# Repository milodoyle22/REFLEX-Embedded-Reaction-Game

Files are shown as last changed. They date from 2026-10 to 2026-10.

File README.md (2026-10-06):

# REFLEX - Embedded Reaction-Time Game

REFLEX is a five-round embedded reaction-time game built around an Arduino Mega 2560. It combines embedded C++, digital electronics, transistor-switched illuminated arcade controls, a 16x2 LCD, audio feedback, permanent perfboard hardware, and a custom enclosure designed in Fusion 360 for 3D printing.

> **Build status:** Core electronics, firmware, perfboard transfer, and enclosure CAD are complete. Final enclosure assembly and full-system validation are still in progress.

## Demo

A working breadboard prototype demonstrates randomized cues, reaction-time measurement, scoring, LCD feedback, and wrong-button handling before the design was transferred to permanent hardware.

**[Watch the REFLEX breadboard prototype demo](docs/demo/REFLEX_Prototype_Demo.mp4)**

## Engineering Highlights

- Built a complete five-round reaction game around an Arduino Mega 2560
- Structured the firmware as a finite-state machine rather than a blocking sequence
- Replaced the original blocking wait logic with non-blocking timing so early presses can be detected
- Measured the illuminated arcade-button LED load at approximately **22 mA**
- Added three 2N2222A NPN low-side driver stages instead of placing the LED load directly on MCU GPIO
- Used Arduino internal pull-ups for simple, reliable active-low button inputs
- Migrated the validated breadboard circuit to soldered perfboard with dedicated +5 V and GND distribution
- Designed a serviceable enclosure in Fusion 360 around the real component dimensions

## System Overview

| Subsystem | Implementation |
| --- | --- |
| Controller | Arduino Mega 2560 |
| Inputs | Red, green, blue, and START arcade-button switches |
| Outputs | 3 illuminated color cues, 16x2 LCD, passive buzzer |
| LED drivers | 3x 2N2222A NPN transistor low-side switches |
| Permanent hardware | Custom soldered perfboard |
| Mechanical design | Fusion 360 enclosure for 3D printing |
| Power | Designed for internal USB power-bank operation |

### Signal Map

| Function | Arduino Pin |
| --- | ---: |
| Blue LED driver | D4 |
| Green LED driver | D5 |
| Red LED driver | D6 |
| Red button | D8 |
| Green button | D9 |
| Blue button | D10 |
| START button | D11 |
| Passive buzzer | D12 |
| LCD RS | D22 |
| LCD E | D23 |
| LCD D4 | D24 |
| LCD D5 | D25 |
| LCD D6 | D26 |
| LCD D7 | D27 |

## Firmware Architecture

The firmware uses five states:

~~~mermaid
stateDiagram-v2
    [*] --> IDLE
    IDLE --> WAITING: START
    WAITING --> RESULT: false start
    WAITING --> CUE_ACTIVE: randomized wait expires
    CUE_ACTIVE --> RESULT: correct or wrong input
    RESULT --> WAITING: next round
    RESULT --> GAME_OVER: round 5 complete
    GAME_OVER --> IDLE: START / reset
~~~

- **IDLE** - waits for the player to start
- **WAITING** - runs a randomized 2-5 second delay while still checking for false starts
- **CUE_ACTIVE** - activates one randomized color cue and measures response time
- **RESULT** - reports the round result and waits to continue
- **GAME_OVER** - displays final score and average successful reaction time

Reaction time is captured with **micros()**, while the waiting state uses non-blocking **millis()** timing so the program can continue checking inputs before the cue appears.

## Hardware Design

The illuminated arcade-button LEDs were measured at approximately **22 mA**. REFLEX therefore uses a transistor stage for each colored LED instead of driving the load directly from an Arduino output.

~~~text
Arduino output -> 1 kOhm -> transistor base
+5 V -> 220 Ohm -> button LED +
button LED - -> transistor collector
transistor emitter -> GND
~~~

The red, green, blue, and START switches use **INPUT_PULLUP**, so each input is HIGH when released and LOW when pressed. The white START-button LED is continuously illuminated as a status indicator.

## Development Process

The project was developed and validated incrementally:

1. Breadboarded the LCD, buzzer, input buttons, and cue LEDs
2. Wrote and debugged the initial reaction-game firmware
3. Identified the limitation of a blocking randomized delay
4. Reworked the game flow into a non-blocking finite-state machine
5. Measured the arcade-button LED current and added transistor drivers
6. Tested all three color-driver channels
7. Transferred the working circuit to soldered perfboard
8. Designed the enclosure around the actual Mega, perfboard, LCD, controls, and power hardware
9. Exported the printable enclosure parts and submitted them for 3D printing

## CAD Files

Printable enclosure exports are available in [cad/stl/](cad/stl/):

- [REFLEX_Shell.stl](cad/stl/REFLEX_Shell.stl)
- [REFLEX_Cover.stl](cad/stl/REFLEX_Cover.stl)
- [REFLEX_Coupon.stl](cad/stl/REFLEX_Coupon.stl)

The coupon is a small print used to validate fit/tolerance before committing to the full enclosure print.

## Repository Structure

~~~text
REFLEX-Embedded-Reaction-Game/
|-- README.md
|-- firmware/
|   |-- REFLEX.ino
|   `-- README.md
|-- hardware/
|   |-- README.md
|   `-- pinout.md
|-- cad/
|   |-- README.md
|   `-- stl/
|-- docs/
|   |-- demo/
|   `-- images/
`-- bom/
    `-- BOM.md
~~~

## Current Build Status

- [x] Breadboard prototype
- [x] Core game firmware
- [x] Non-blocking FSM timing
- [x] LCD interface
- [x] False-start and wrong-button logic
- [x] Transistor LED drivers
- [x] Perfboard transfer
- [x] Three-channel LED hardware test
- [x] Fusion 360 enclosure design
- [x] STL exports
- [x] Enclosure submitted for 3D printing
- [x] Breadboard prototype demo video
- [ ] Final enclosure assembly
- [ ] Final integrated system test
- [ ] Final assembled-device photos
- [ ] Final assembled-device demo

## Tools and Technologies

**Hardware:** Arduino Mega 2560, 2N2222A transistors, 16x2 LCD, illuminated arcade buttons, passive buzzer, perfboard

**Software:** Arduino IDE, C++, Fusion 360, Git/GitHub

**Test Equipment:** Digital multimeter, oscilloscope, bench power supply

**Fabrication:** Breadboarding, soldering, perfboard assembly, 3D printing

## Author

**Milo Doyle**  
Electrical Engineering Student  
California State University, Long Beach  
Expected Graduation: May 2028

---

This repository documents an ongoing engineering build. Final enclosure photos and integrated-system results will be added after assembly.

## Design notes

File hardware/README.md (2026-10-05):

# Hardware

This directory documents the electrical design and permanent perfboard implementation for REFLEX.

## Subdirectories
- `schematic/` - circuit diagrams and electrical schematics
- `perfboard/` - perfboard layout and build documentation
- `wiring/` - wiring diagrams and harness documentation

## Major Hardware
- Arduino Mega 2560
- 3 x 2N2222A NPN transistor LED drivers
- 3 x 1 kOhm transistor base resistors
- 5 x 220 Ohm LED/backlight current-limiting resistors
- 4 x illuminated arcade buttons
- 16x2 HD44780-style LCD
- 10 kOhm LCD contrast potentiometer
- passive buzzer
- custom perfboard
- internal USB power bank

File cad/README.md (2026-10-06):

# CAD

Mechanical design files for the REFLEX enclosure.

## Design Tool

Autodesk Fusion 360

## Printable Parts

STL exports are stored in [stl/](stl/):

- **REFLEX_Shell.stl** - main enclosure body
- **REFLEX_Cover.stl** - removable cover
- **REFLEX_Coupon.stl** - small fit/tolerance test print

## Design Requirements

The enclosure was designed around the Arduino Mega 2560, custom perfboard, 16x2 LCD, four 30 mm illuminated arcade buttons, an internal slim USB power bank, and a short USB-A to USB-B power cable.

The layout prioritizes service access and keeps the Mega, perfboard, and battery from being stacked directly on top of one another.

The enclosure has been submitted for 3D printing; final fit and full-system assembly are still pending.

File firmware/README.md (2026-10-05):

# Firmware

This directory contains the Arduino firmware for REFLEX.

## Target
- Arduino Mega 2560
- Arduino IDE
- C++

## Main Firmware
The final game firmware will live here as `REFLEX.ino`.

The firmware implements the game as a finite-state machine and handles button inputs, random cue timing, reaction-time measurement, false starts, wrong-button responses, scoring, LCD output, buzzer feedback, and illuminated button control.

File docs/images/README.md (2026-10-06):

# Project Images

This directory contains development photos from the REFLEX build.

## Current Photos

The current files document the breadboard-prototype stage and are retained as original HEIC captures in the **raw/** folder.

Key prototype shots include:

- **breadboard-start-screen.HEIC**
- **breadboard-hardware-closeup.HEIC**
- **breadboard-wrong-button.HEIC**
- **breadboard-game-over.HEIC**

Additional development photos are also retained in **raw/**.

Final assembled-device photos will be added after the enclosure is printed and the complete system is integrated. JPG/PNG versions of the strongest images can then be embedded directly in the main README.

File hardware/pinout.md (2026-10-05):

# REFLEX Pinout

## Arduino Mega 2560

| Function | Pin | Direction |
| --- | ---: | --- |
| Blue LED transistor driver | D4 | Output |
| Green LED transistor driver | D5 | Output |
| Red LED transistor driver | D6 | Output |
| Red arcade switch | D8 | Input pull-up |
| Green arcade switch | D9 | Input pull-up |
| Blue arcade switch | D10 | Input pull-up |
| START arcade switch | D11 | Input pull-up |
| Passive buzzer | D12 | Output |
| LCD RS | D22 | Output |
| LCD E | D23 | Output |
| LCD D4 | D24 | Output |
| LCD D5 | D25 | Output |
| LCD D6 | D26 | Output |
| LCD D7 | D27 | Output |

## Arcade Button Wiring

### Red / Green / Blue LED Channels

```text
Arduino output -> 1 kOhm -> NPN base
NPN emitter -> GND
NPN collector -> button LED negative
+5 V -> 220 Ohm -> button LED positive
```

### Switch Inputs

```text
Arduino input -> switch -> GND
```

The firmware uses `INPUT_PULLUP`, so released = HIGH and pressed = LOW.

## White START Button

```text
D11 -> switch -> GND

+5 V -> 220 Ohm -> START LED +
START LED - -> GND
```

The white START LED is always illuminated while the system is powered.

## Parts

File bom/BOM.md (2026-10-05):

# Bill of Materials

## Core Electronics

| Qty | Component | Notes |
| ---: | --- | --- |
| 1 | Arduino Mega 2560 | Main microcontroller |
| 1 | 16x2 LCD | HD44780-style character display |
| 4 | 30 mm illuminated arcade buttons | Red, green, blue, white |
| 3 | 2N2222A NPN transistors | Colored LED switching |
| 3 | 1 kOhm resistors | Transistor base resistors |
| 5 | 220 Ohm resistors | Arcade LEDs + LCD backlight |
| 1 | 10 kOhm potentiometer | LCD contrast |
| 1 | Passive buzzer | Audio feedback |
| 1 | Perfboard | Permanent circuit assembly |
| 1 | USB power bank | Internal power source |
| 1 | Short USB-A to USB-B cable | Power bank to Arduino Mega |

## Fabrication / Wiring
- hookup wire / jumper wire
- solder
- headers/connectors as required
- 3D-printed enclosure
- enclosure fasteners

## Test Equipment Used
- digital multimeter
- oscilloscope
- bench power supply
- soldering iron

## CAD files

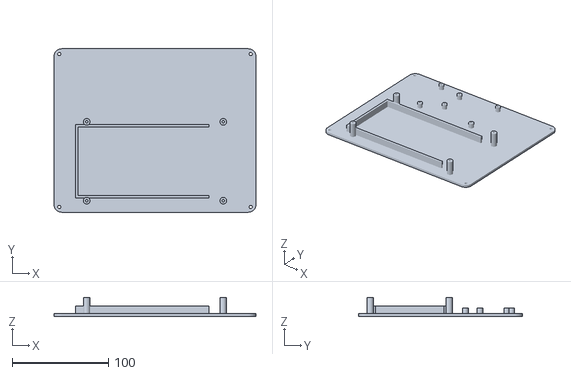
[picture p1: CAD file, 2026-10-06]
cad/stl/REFLEX_Cover.stl
210.0 x 170.0 x 20.0

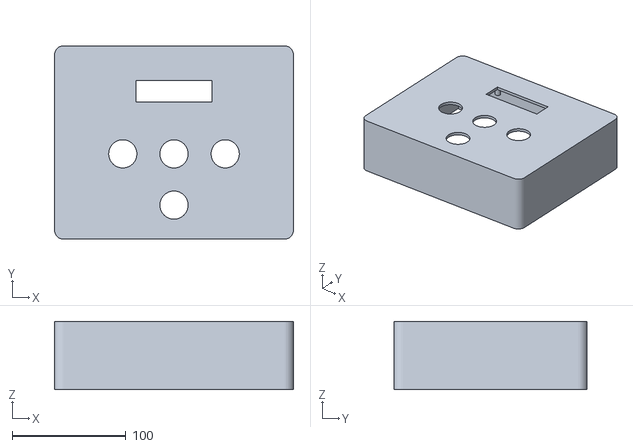
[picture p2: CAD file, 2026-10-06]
cad/stl/REFLEX_Shell.stl
210.0 x 170.0 x 60.0

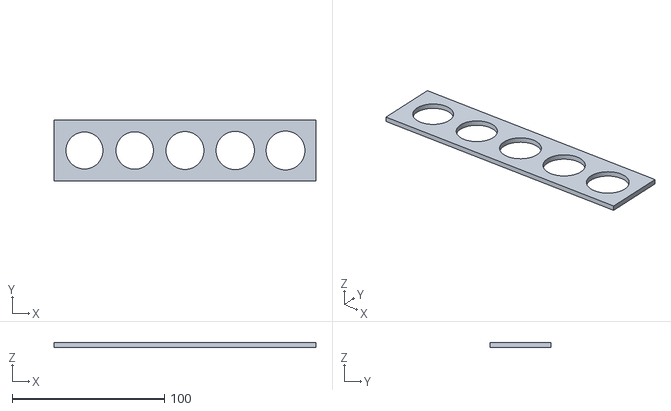
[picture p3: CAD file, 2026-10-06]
cad/stl/REFLEX_Coupon.stl
172.0 x 40.0 x 3.00

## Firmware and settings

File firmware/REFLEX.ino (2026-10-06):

#include <LiquidCrystal.h>

// =====================================================
// REFLEX - 5 Round Reaction Game
// =====================================================
/*
  Features:
  - 3 color reaction inputs
  - Randomized cue timing
  - False-start detection
  - Wrong-button detection
  - Reaction-time measurement
  - 5-round scoring
  - LCD feedback
  - Audio feedback
  - Finite-state-machine architecture

  Hardware:
  - Arduino Mega 2560
  - 3 response buttons
  - 1 start button
  - 3 LEDs
  - 16x2 LCD
  - Passive buzzer
*/

// ---------------- LEDs ----------------

const int RED_LED   = 6;
const int GREEN_LED = 5;
const int BLUE_LED  = 4;

// ---------------- Buttons ----------------
// Buttons use the Mega's internal pull-up resistors; each switch connects its input pin to GND when pressed
const int RED_BUTTON   = 8;
const int GREEN_BUTTON = 9;
const int BLUE_BUTTON  = 10;
const int START_BUTTON = 11;

// ---------------- Buzzer ----------------
// Provides audible feedback for correct and incorrect responses
const int BUZZER_PIN = 12;

// ---------------- LCD ----------------
// Connected to 10k potentiometer to adjust screen contrast
// RS = 22
// E  = 23
// D4 = 24
// D5 = 25
// D6 = 26
// D7 = 27

LiquidCrystal lcd(22, 23, 24, 25, 26, 27);

// =====================================================
// GAME STATES
// =====================================================

enum GameState
{
    IDLE,
    WAITING,
    CUE_ACTIVE,
    RESULT,
    GAME_OVER
};

GameState currentState = IDLE;

// =====================================================
// GAME SETTINGS
// =====================================================

const int TOTAL_ROUNDS = 5;

// =====================================================
// GAME VARIABLES
// =====================================================

int currentRound = 0;
int score = 0; // start game at 0

int activeColor = -1;

unsigned long totalReactionTime = 0;
unsigned long bestReactionTime = 0;

int successfulReactions = 0;

// =====================================================
// TIMING
// =====================================================

unsigned long waitingStartTime = 0;
unsigned long randomWaitTime = 0;

unsigned long reactionStartTime = 0;
unsigned long reactionEndTime = 0;

// =====================================================
// BUTTON STATE TRACKING
//
// INPUT_PULLUP:
//
// HIGH = released
// LOW  = when pressed
// =====================================================

bool prevRedState   = HIGH;
bool prevGreenState = HIGH;
bool prevBlueState  = HIGH;
bool prevStartState = HIGH;

// =====================================================
// SETUP
// =====================================================

void setup()
{
    pinMode(RED_LED, OUTPUT);
    pinMode(GREEN_LED, OUTPUT);
    pinMode(BLUE_LED, OUTPUT);
    // Internal pull-ups provide a defined HIGH state while buttons are released
    pinMode(RED_BUTTON, INPUT_PULLUP);
    pinMode(GREEN_BUTTON, INPUT_PULLUP);
    pinMode(BLUE_BUTTON, INPUT_PULLUP);
    pinMode(START_BUTTON, INPUT_PULLUP);

    pinMode(BUZZER_PIN, OUTPUT);

    Serial.begin(9600);

    lcd.begin(16, 2);

    randomSeed(analogRead(A0));

    allLedsOff();
    noTone(BUZZER_PIN);

    showIdleScreen();
// Start Screen:
    Serial.println("REFLEX");
    Serial.println("Press START to begin.");
}

// =====================================================
// MAIN LOOP
// =====================================================

void loop()
{
    bool redState   = digitalRead(RED_BUTTON);
    bool greenState = digitalRead(GREEN_BUTTON);
    bool blueState  = digitalRead(BLUE_BUTTON);
    bool startState = digitalRead(START_BUTTON);

    bool redPressed =
        (redState == LOW && prevRedState == HIGH);

    bool greenPressed =
        (greenState == LOW && prevGreenState == HIGH);

    bool bluePressed =
        (blueState == LOW && prevBlueState == HIGH);

    bool startPressed =
        (startState == LOW && prevStartState == HIGH);

    switch (currentState) // Game behavior is controlled by the current FSM state
    {
        case IDLE:

            if (startPressed)
            {
                resetGame();
                startRound();
            }

            break;

        case WAITING: // Detect early presses before the cue becomes active

            if (redPressed || greenPressed || bluePressed)
            {
                handleFalseStart();
            }

            else if (millis() - waitingStartTime >= randomWaitTime)
            {
                activateCue();
            }

            break;

        case CUE_ACTIVE:

            if (redPressed || greenPressed || bluePressed)
            {
                reactionEndTime = micros();

                int pressedColor =
                    getPressedColor(
                        redPressed,
                        greenPressed,
                        bluePressed
                    );

                allLedsOff();

                if (pressedColor == activeColor)
                {
                    handleCorrectResponse();
                }
                else
                {
                    handleWrongResponse(); // Wrong button ends the round with 0 points.
                }
            }

            break;

        case RESULT:

            if (startPressed) // Continue to the next round or show final results after round 5.
            {
                if (currentRound >= TOTAL_ROUNDS)
                {
                    showGameOver();
                }
                else
                {
                    startRound();
                }
            }

            break;

        case GAME_OVER:

            if (startPressed)
            {
                resetGame();
                startRound();
            }

            break;
    }
// Wrong buttons and false starts score 0 points; no time penalty is added.
    prevRedState   = redState;
    prevGreenState = greenState;
    prevBlueState  = blueState;
    prevStartState = startState;
}

// =====================================================
// RESET GAME
// =====================================================

void resetGame() // START acts as the main action button for beginning, continuing, and restarting the game
{
    currentRound = 0;
    score = 0;

    totalReactionTime = 0;
    bestReactionTime = 0;

    successfulReactions = 0;

    allLedsOff();
    noTone(BUZZER_PIN);

    Serial.println();
    Serial.println("==============================");
    Serial.println("NEW GAME");
    Serial.println("==============================");
}

// =====================================================
// START ROUND
// =====================================================

void startRound()
{
    currentRound++;

    allLedsOff();
    noTone(BUZZER_PIN);

    randomWaitTime = random(2000, 5001);
    waitingStartTime = millis();

    lcd.clear();

    lcd.print("Round ");
    lcd.print(currentRound);
    lcd.print("/");
    lcd.print(TOTAL_ROUNDS);

    lcd.setCursor(0, 1);
    lcd.print("GET READY...");

    Serial.println();
    Serial.print("ROUND ");
    Serial.print(currentRound);
    Serial.print("/");
    Serial.println(TOTAL_ROUNDS);

    Serial.println("GET READY...");

    currentState = WAITING;
}

// =====================================================
// ACTIVATE RANDOM CUE
// =====================================================

void activateCue()
{
    activeColor = random(0, 3);

    allLedsOff();

    lcd.clear();

    if (activeColor == 0)
    {
        digitalWrite(RED_LED, HIGH);

        lcd.print("RED!");
        Serial.println("RED!");
    }

    else if (activeColor == 1)
    {
        digitalWrite(GREEN_LED, HIGH);

        lcd.print("GREEN!");
        Serial.println("GREEN!");
    }

    else
    {
        digitalWrite(BLUE_LED, HIGH);

        lcd.print("BLUE!");
        Serial.println("BLUE!");
    }

    lcd.setCursor(0, 1);
    lcd.print("GO!");

    reactionStartTime = micros();

    currentState = CUE_ACTIVE;
}

// =====================================================
// FALSE START
// =====================================================

void handleFalseStart()
{
    allLedsOff();

    tone(BUZZER_PIN, 200, 500);

    lcd.clear();
    lcd.print("FALSE START!");

    lcd.setCursor(0, 1);
    lcd.print("0 POINTS");

    Serial.println();
    Serial.println("FALSE START!");
    Serial.println("0 POINTS");

    prepareForNextRound();
}

// =====================================================
// WRONG RESPONSE
// =====================================================

void handleWrongResponse()
{
    tone(BUZZER_PIN, 300, 350);

    lcd.clear();
    lcd.print("WRONG BUTTON!");

    lcd.setCursor(0, 1);
    lcd.print("0 POINTS");

    Serial.println();
    Serial.println("WRONG BUTTON!");
    Serial.println("0 POINTS");

    prepareForNextRound();
}

// =====================================================
// CORRECT RESPONSE
// =====================================================

void handleCorrectResponse()
{
    unsigned long reactionUs =
        reactionEndTime - reactionStartTime;

    unsigned long reactionMs =
        reactionUs / 1000;

    score++;

    successfulReactions++;

    totalReactionTime += reactionMs;

    if (bestReactionTime == 0 ||
        reactionMs < bestReactionTime)
    {
        bestReactionTime = reactionMs;
    }

    tone(BUZZER_PIN, 1200, 150);

    lcd.clear();

    lcd.print("CORRECT! +1");

    lcd.setCursor(0, 1);

    lcd.print(reactionMs);
    lcd.print(" ms");

    Serial.println();
    Serial.println("CORRECT!");

    Serial.print("Reaction Time: ");
    Serial.print(reactionMs);
    Serial.println(" ms");

    Serial.print("Score: ");
    Serial.print(score);
    Serial.print("/");
    Serial.println(TOTAL_ROUNDS);

    prepareForNextRound();
}

// =====================================================
// PREPARE RESULT STATE
// =====================================================

void prepareForNextRound()
{
    Serial.println();
    Serial.println("Press START to continue.");

    currentState = RESULT;
}

// =====================================================
// GAME OVER
// =====================================================

void showGameOver()
{
    allLedsOff();
    noTone(BUZZER_PIN);

    currentState = GAME_OVER;

    lcd.clear();

    lcd.print("GAME OVER ");
    lcd.print(score);
    lcd.print("/");
    lcd.print(TOTAL_ROUNDS);

    lcd.setCursor(0, 1);

    if (successfulReactions > 0)
    {
        unsigned long average =
            totalReactionTime / successfulReactions;

        lcd.print("AVG ");
        lcd.print(average);
        lcd.print(" ms");
    }
    else
    {
        lcd.print("AVG N/A");
    }

    Serial.println();
    Serial.println("==============================");
    Serial.println("GAME OVER");
    Serial.println("==============================");

    Serial.print("Score: ");
    Serial.print(score);
    Serial.print("/");
    Serial.println(TOTAL_ROUNDS);

    if (successfulReactions > 0)
    {
        unsigned long average =
            totalReactionTime / successfulReactions;

        Serial.print("Average Reaction: ");
        Serial.print(average);
        Serial.println(" ms");

        Serial.print("Best Reaction: ");
        Serial.print(bestReactionTime);
        Serial.println(" ms");
    }
    else
    {
        Serial.println("Average Reaction: N/A");
        Serial.println("Best Reaction: N/A");
    }

    Serial.println();
    Serial.println("Press START for a new game.");
}

// =====================================================
// DETERMINE PRESSED COLOR
// =====================================================

int getPressedColor(
    bool redPressed,
    bool greenPressed,
    bool bluePressed
)
{
    if (redPressed)
        return 0;

    if (greenPressed)
        return 1;

    if (bluePressed)
        return 2;

    return -1;
}

// =====================================================
// TURN OFF ALL LEDs
// =====================================================

void allLedsOff()
{
    digitalWrite(RED_LED, LOW);
    digitalWrite(GREEN_LED, LOW);
    digitalWrite(BLUE_LED, LOW);
}

// =====================================================
// IDLE SCREEN
// =====================================================

void showIdleScreen()
{
    lcd.clear();

    lcd.print("     REFLEX");

    lcd.setCursor(0, 1);
    lcd.print("PRESS START");
}

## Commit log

2026-10-06 Add REFLEX Arduino firmware
2026-10-06 Add prototype demo link and organize video
2026-10-06 Polish project documentation and organize CAD assets
    [REFLEX_Coupon.stl, REFLEX_Cover.stl, REFLEX_Shell.stl]
